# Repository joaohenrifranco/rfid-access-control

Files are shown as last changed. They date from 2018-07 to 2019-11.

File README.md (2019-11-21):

_Note: this repo is not being actively maintained_
# RFID Access Control
Access control system developed to log each entrance and exit of internal rooms at a lab located at Federal University of Rio de Janeiro (UFRJ).

## Server
Django based server that provides a RESTful API for authentication and logging. Also provides a control panel made with Django Admin.

Code and more detailed info inside `server/`
## Client
Developed and tested for Arduino Mega using [PlatformIO](https://platformio.org/).

Works primarily with RFID readers, one for outside and one for inside, checking if the read UID is registered in server database and has sufficient privileges for unlocking the desired room.

Password authentication is optional through a 4x3 matrix keyboard, providing some kind of security.

Code and more detailed info inside `client/`

## Extras

### Front door "smart doorbell"
Developed in parallel with this project. Works with a RaspberryPi 3 located at the front door and a VoIP server (Asterisk) for live video transferring.

When doorbell is rang, the raspberry calls all people inside the lab, with some preconfigured order. They can take the call, check the camera and open the door if desired. All with their smartphone, PC or any other SIP-capable device.

Employees can automatically get in with their RFID tags registered in this system.

Also, everything is logged through this API.

For code and more info on that check the repositories below:

 - [Asterisk server](https://github.com/joaohenriquef/asterisk-smartdoor)
 - [Raspberry client](https://github.com/joaohenriquef/rasp-smartdoor)

## Disclaimer

Note that it is not made with security in mind and its main purpouse is internal logging, therefore it may be vulnerable to external attackers.

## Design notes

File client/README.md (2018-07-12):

# Client

## Disclaimer
Every instruction shown below is only valid for this single project. Any changes on code, hardware or others may cause malfunctions or adding other requirements.

## Hardware requirements
For a single Arduino client you will need:
* 1x Arduino MEGA 2560;
* 1x Ethernet Shield W5100 (for communicating with server);
* 2x RFID Reader MFRC-522 (for reading UIDs);
* 2x RGB LED;
* 1x 5V active buzzer;
* 1x TCRT5000 optical sensor (for checking if the door is closed or not);
* 1x LM2596 DC/DC converter (for supplying Arduino through a 12V power source);
* 1x MOSFET IRF540N (for unlocking the door);
* 3x 150Ω resistors (for RED pins on LEDs and infra-red LED);
* 2x 220Ω resistors (for GREEN pins on LEDs);
* 2x 470Ω resistors (for BLUE pins on LEDs);
* 1x 10KΩ resistor (for LDR);
* 1x 4x3 matrix keypad (optional);
* 1x Custom shield*

*For further information on this, check the [Custom shield](#custom-shield) section on this file.

## Implementation
A single client consists on two "blocks" of equipment. One block inside the room and, the other, outside, as shown below:

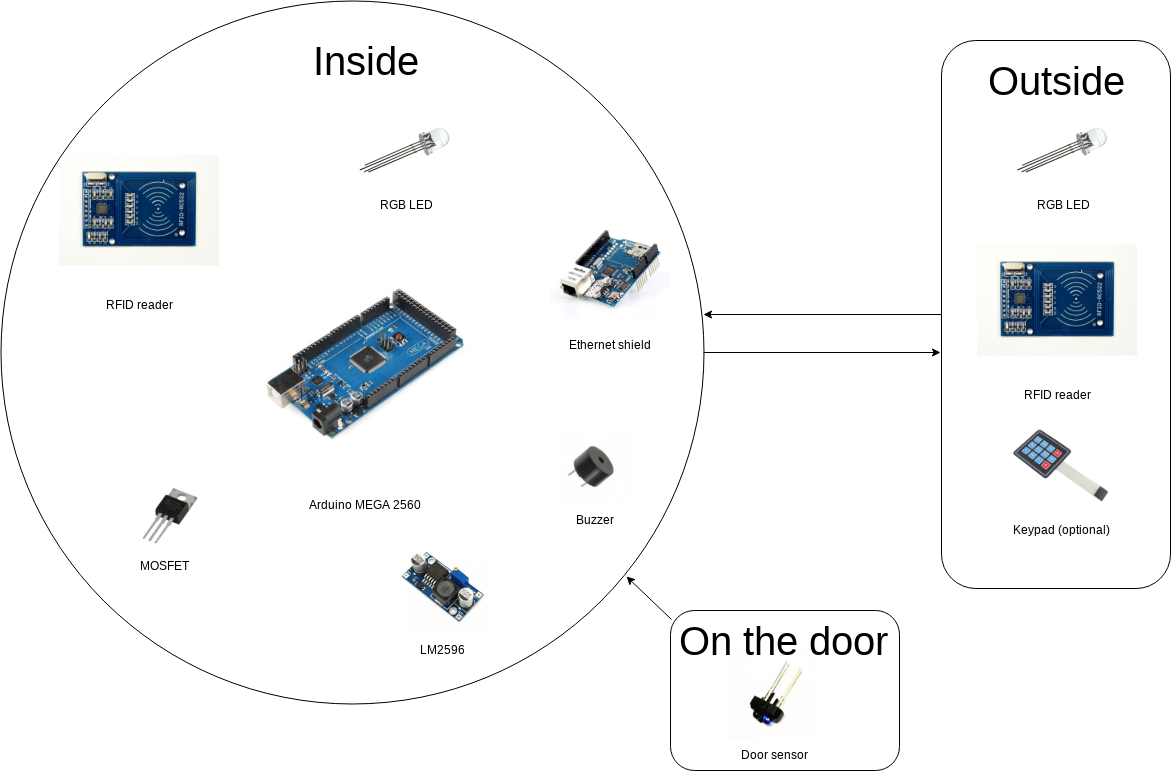
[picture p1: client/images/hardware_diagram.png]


## Algorithm
The Arduino code is pretty simple and works as the diagram below:
* Setup:

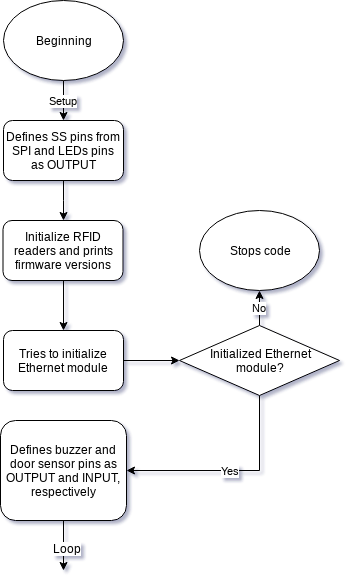
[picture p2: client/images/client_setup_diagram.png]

* Loop:

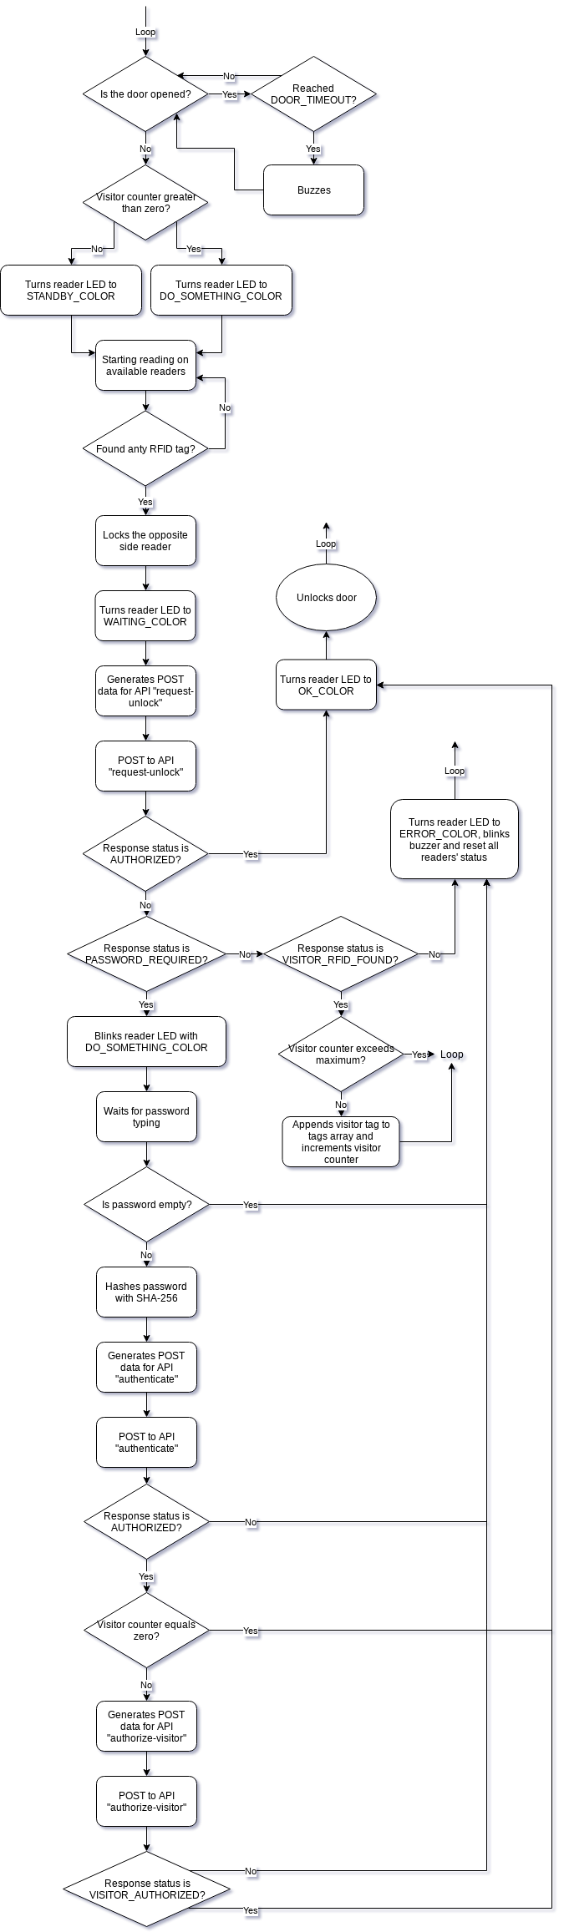
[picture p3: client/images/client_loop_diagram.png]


## Custom shield
In order to ease implementation, a custom PCB was designed with [KiCad](http://kicad-pcb.org/), in the shape of an Arduino Mega Shield. The electrical schematic is the following and all the files related to the PCB design may be found inside `custom_shield/`:

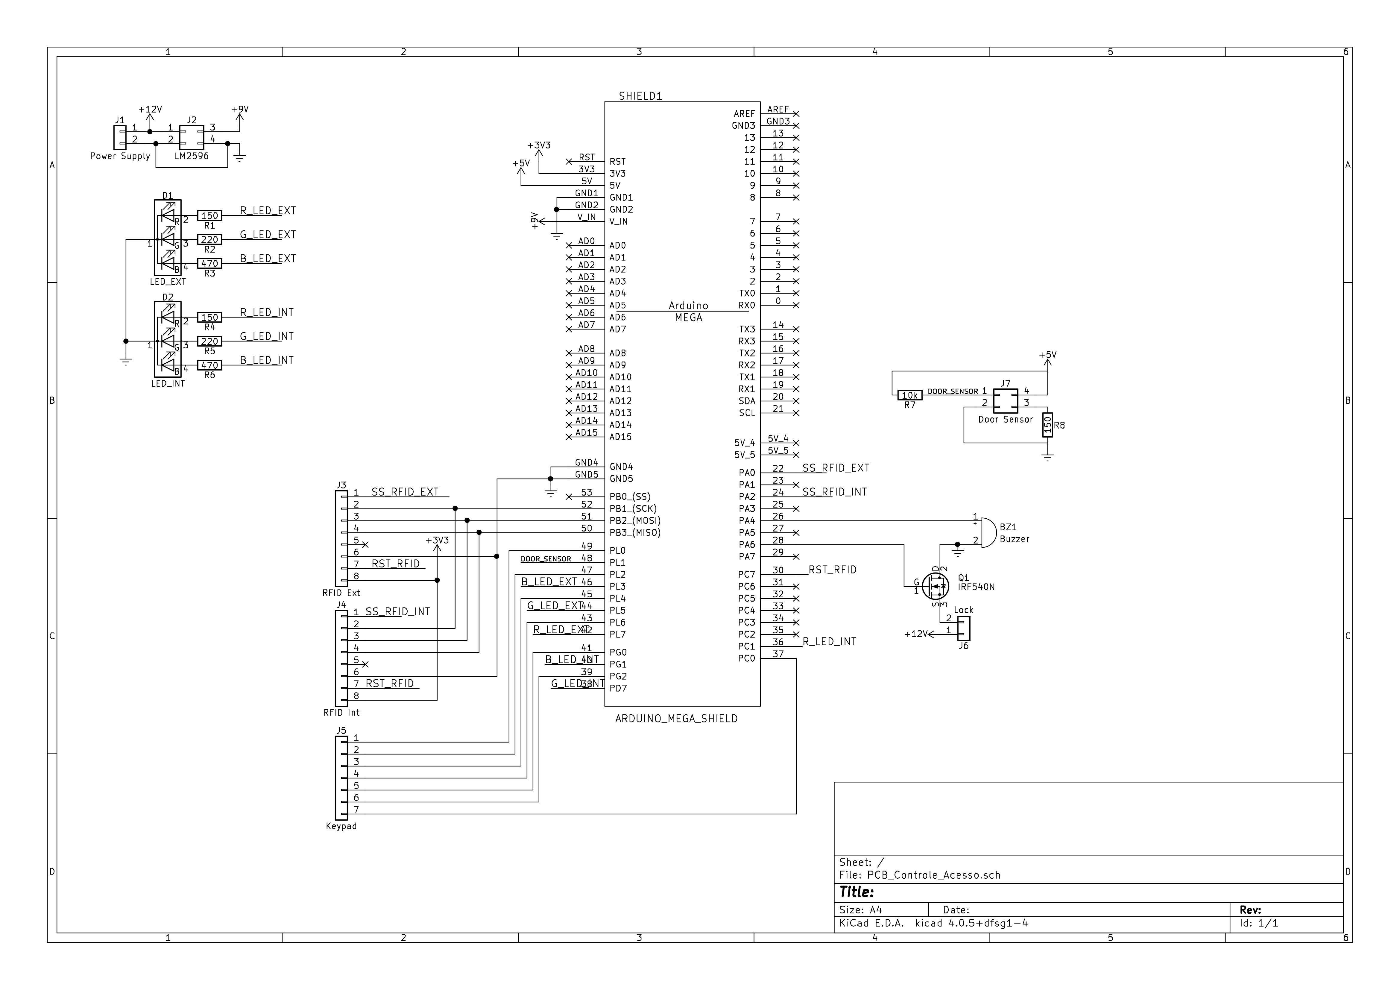
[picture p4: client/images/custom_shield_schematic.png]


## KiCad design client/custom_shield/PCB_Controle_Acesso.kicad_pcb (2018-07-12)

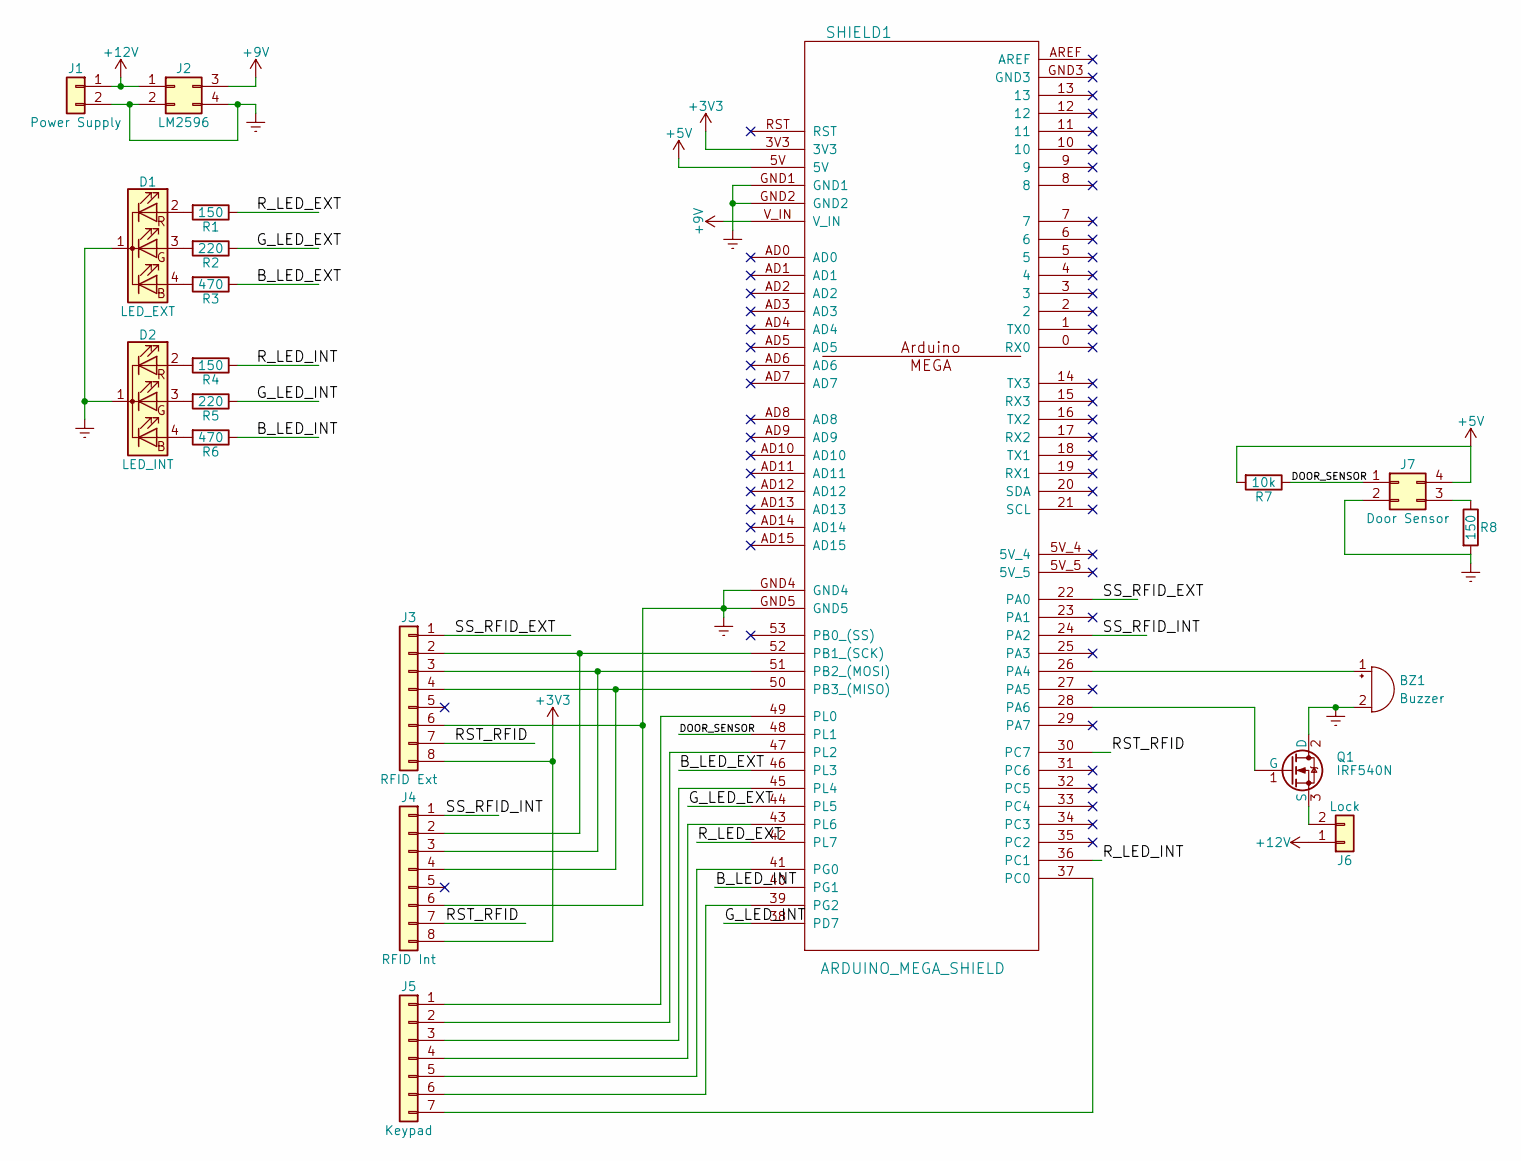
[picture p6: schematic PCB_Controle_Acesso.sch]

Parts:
BZ1: Buzzer; Buzzer_12x9.5RM7.6
D1: LED_EXT; Pin_Header_Straight_1x04_Pitch2.54mm
D2: LED_INT; LED_D5.0mm-4
J1: Power Supply; TerminalBlock_Phoenix_MKDS1.5-2pol
J2: LM2596; lm2596
J3: RFID Ext; Pin_Header_Straight_1x08_Pitch2.54mm
J4: RFID Int; RFID-RC522
J5: Keypad; Pin_Header_Straight_1x07_Pitch2.54mm
J6: Lock; TerminalBlock_Phoenix_MKDS1.5-2pol
J7: Door Sensor; Pin_Header_Straight_2x02_Pitch2.54mm
Q1: IRF540N; TO-220-3_Horizontal
R1, R4, R8: 150; R_Axial_DIN0204_L3.6mm_D1.6mm_P7.62mm_Horizontal
R2, R5: 220; R_Axial_DIN0204_L3.6mm_D1.6mm_P7.62mm_Horizontal
R3, R6: 470; R_Axial_DIN0204_L3.6mm_D1.6mm_P7.62mm_Horizontal
R7: 10k; R_Axial_DIN0204_L3.6mm_D1.6mm_P7.62mm_Horizontal
SHIELD1: ARDUINO_MEGA_SHIELD; ARDUINO_MEGA_SHIELD_ETH_MODIFIED

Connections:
+5V: J7.4, R7.2, SHIELD1.5V
+9V: J2.3, SHIELD1.V_IN
+12V: J1.1, J2.1, J6.1
/B_LED_EXT: R3.1, SHIELD1.46 (PL3)
/B_LED_INT: R6.1, SHIELD1.40 (PG1)
/DOOR_SENSOR: J7.1, R7.1, SHIELD1.48 (PL1)
/G_LED_EXT: R2.1, SHIELD1.44 (PL5)
/G_LED_INT: R5.1, SHIELD1.38 (PD7)
/RST_RFID: J3.7, J4.7, SHIELD1.30 (PC7)
/R_LED_EXT: R1.1, SHIELD1.42 (PL7)
/R_LED_INT: R4.1, SHIELD1.36 (PC1)
/SS_RFID_EXT: J3.1, SHIELD1.22 (PA0)
/SS_RFID_INT: J4.1, SHIELD1.24 (PA2)
unnamed: BZ1.1 (-), SHIELD1.26 (PA4)
unnamed: D1.2 (RA), R1.2
unnamed: D1.3 (GA), R2.2
unnamed: D1.4 (BA), R3.2
unnamed: D2.2 (RA), R4.2
unnamed: D2.3 (GA), R5.2
unnamed: D2.4 (BA), R6.2
unnamed: J3.2, J4.2, SHIELD1.52 (PB1_(SCK))
unnamed: J3.3, J4.3, SHIELD1.51 (PB2_(MOSI))
unnamed: J3.4, J4.4, SHIELD1.50 (PB3_(MISO))
unnamed: J5.1, SHIELD1.49 (PL0)
unnamed: J5.2, SHIELD1.47 (PL2)
unnamed: J5.3, SHIELD1.45 (PL4)
unnamed: J5.4, SHIELD1.43 (PL6)
unnamed: J5.5, SHIELD1.41 (PG0)
unnamed: J5.6, SHIELD1.39 (PG2)
unnamed: J5.7, SHIELD1.37 (PC0)
unnamed: J6.2, Q1.3 (S)
unnamed: J7.3, R8.1
unnamed: Q1.1 (G), SHIELD1.28 (PA6)

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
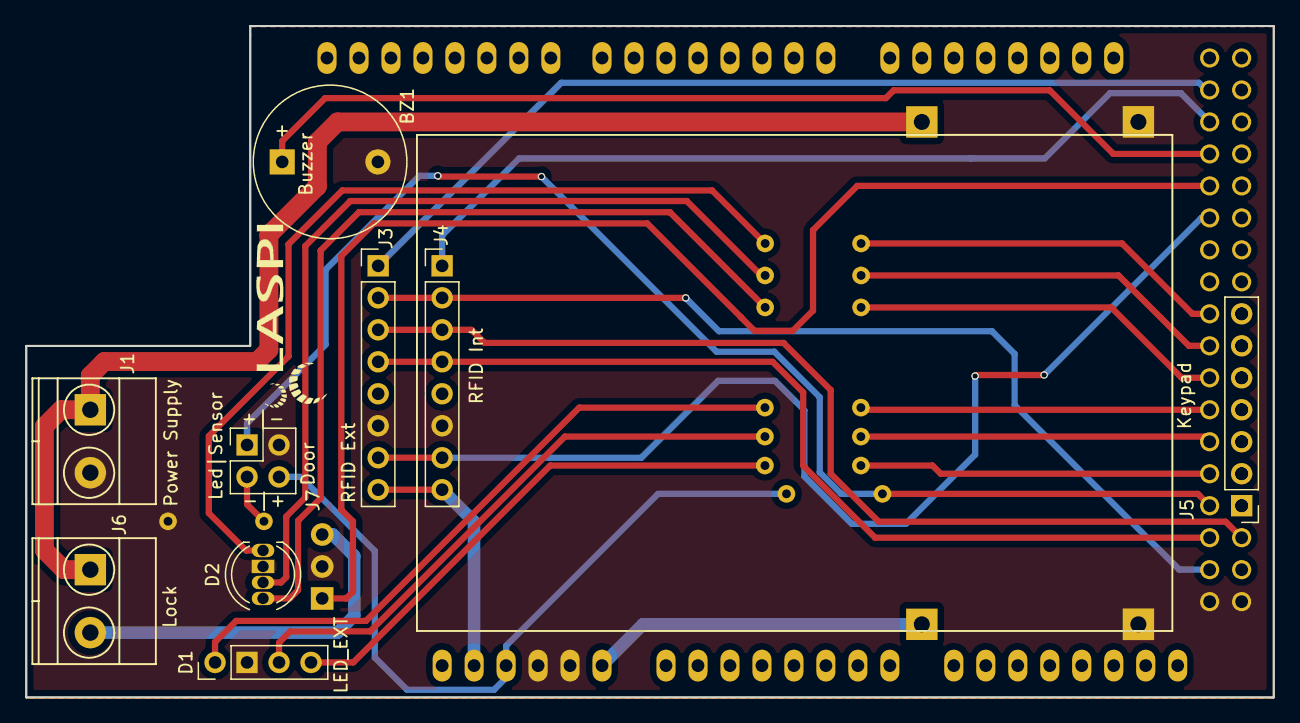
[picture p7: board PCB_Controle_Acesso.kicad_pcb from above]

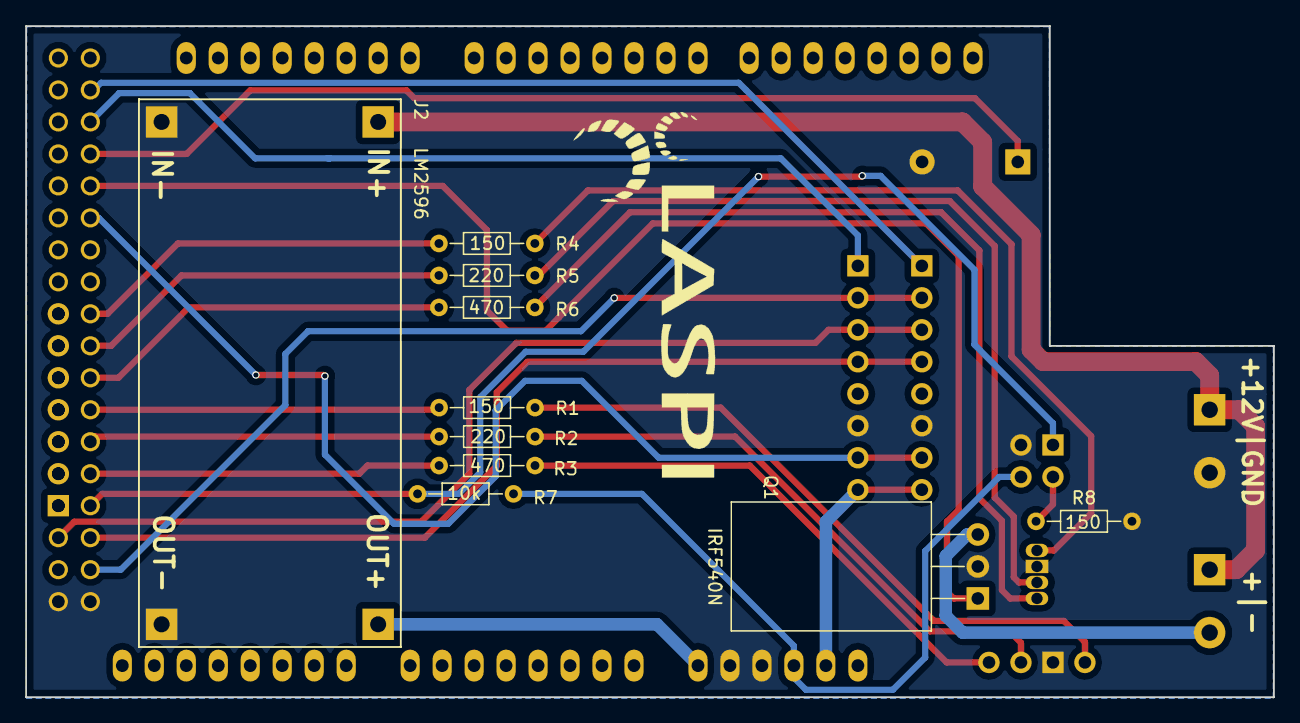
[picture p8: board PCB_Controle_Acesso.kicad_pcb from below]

Board: 2 copper layers, 99.1 x 53.3 mm, 20 parts (10 on the bottom side), 35 nets.

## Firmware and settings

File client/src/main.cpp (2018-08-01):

/*
 *  This code is compatible with Arduino MEGA 2560 R3
 */

/*
 *  Libraries
 */
#include <SPI.h>
#include <stdio.h>
#include <string.h>
#include <MFRC522.h>
#include <Ethernet.h>
#include <Keypad.h>
#include <sha256.h>
#include <ArduinoJson.h>
#include <ArduinoHttpClient.h>

/*
 *  Macros
 */
#define WHO_AM_I "ENSAIOS_REP"
#define MEASURE_NUMBERS 10
#define MAX_VISITOR_NUM 20
#define SERIAL_SPEED 9600
#define MAC_ADDRESS                        \
	{                                      \
		0x00, 0xAA, 0xBB, 0xCC, 0xDE, 0x02 \
	} // Change MAC for individual modules
#define SERVER_IP "192.168.88.41"
#define REQUEST_UNLOCK "/api/request-unlock"
#define AUTHENTICATE "/api/authenticate"
#define AUTHORIZE_VISITOR "/api/authorize-visitor"
#define REQUEST_PORT 80 //Standard HTTP port
#define KEYPAD_LINES 4
#define KEYPAD_COLUMNS 3
#define KEYS                                                                 \
	{                                                                        \
		{'1', '2', '3'}, {'4', '5', '6'}, {'7', '8', '9'}, { '*', '0', '#' } \
	}
#define END_OF_PASSWORD '#'
#define QUIT_TYPING '*'
#define NUM_READERS 2
byte BLACK[] = {0, 0, 0}; //Turn LED off
byte BLUE[] = {0, 0, HIGH};
byte GREEN[] = {0, HIGH, 0};
byte AQUA[] = {0, HIGH, HIGH}; //Light blue
byte RED[] = {HIGH, 0, 0};
byte FUCHSIA[] = {HIGH, 0, HIGH}; //Kinda purple
byte YELLOW[] = {HIGH, HIGH, 0};
byte WHITE[] = {HIGH, HIGH, HIGH};
#define WAITING_COLOR YELLOW
#define OK_COLOR GREEN
#define ERROR_COLOR RED
#define STANDBY_COLOR WHITE
#define DO_SOMETHING_COLOR BLUE
#define DOOR_UNLOCK_TIME 2000
#define TIMEOUT_VISITOR 20000
#define TIMEOUT_DOOR 60000
#define TIMEOUT_PASSWORD 5000

/*
 *	Server Error Codes
 */
#define UNKNOWN_ERROR -1
#define AUTHORIZED 0
#define RFID_NOT_FOUND 1
#define INSUFFICIENT_PRIVILEGES 2
#define WRONG_PASSWORD 3
#define PASSWORD_REQUIRED 4
#define VISITOR_RFID_FOUND 5
#define VISITOR_AUTHORIZED 6
#define VISITOR_RFID_NOT_FOUND 7
#define ROOM_NOT_FOUND 8
#define OPEN_DOOR_TIMEOUT 9

/*
 *  Pins
 */
#define LED_IN_R 36
#define LED_IN_G 38
#define LED_IN_B 40
#define LED_OUT_R 42
#define LED_OUT_G 44
#define LED_OUT_B 46
#define PIN_SENSOR 48
#define PIN_BUZZER 26
#define DOOR_PIN 28
#define RST_PIN 30
#define KEYPAD_LIN_PINS \
	{                   \
		37, 39, 41, 43  \
	}
#define KEYPAD_COL_PINS \
	{                   \
		45, 47, 49      \
	}

// Macros for reference only
#define MISO_PIN 50
#define MOSI_PIN 51
#define SCK_PIN 52

//	SS pins
const byte SS_PIN_ETHERNET = 10;
const byte SS_PIN_OUTSIDE = 22;
const byte SS_PIN_INSIDE = 24;

//	Redefining Ethernet SS pin
#ifdef ETHERNET_SHIELD_SPI_CS
#undef ETHERNET_SHIELD_SPI_CS
#endif
#define ETHERNET_SHIELD_SPI_CS SS_PIN_ETHERNET

/*
 *  Declaring the RFID modules
 */
const byte ssPins[] = {SS_PIN_OUTSIDE, SS_PIN_INSIDE};
MFRC522 readers[NUM_READERS];
bool readers_locked[2] = {false, false};
char readers_id[2] = {'o', 'i'};

/*
 *  Declaring IP, MAC and the ethernet client itself
 */
// TODO: FIX AUTOMATIC MAC, FOLLOWING COMMENTED LINES CRASH ETHERNET
// #if defined(WIZ550io_WITH_MACADDRESS)
// ;
// #else
byte mac[] = MAC_ADDRESS;

/*
 *  Declaring and initializing the keypad (4x3)
 */
char keys[KEYPAD_LINES][KEYPAD_COLUMNS] = KEYS;
byte keyPadLinPins[KEYPAD_LINES] = KEYPAD_LIN_PINS;
byte keyPadColPins[KEYPAD_COLUMNS] = KEYPAD_COL_PINS;
Keypad keyPad = Keypad(makeKeymap(keys), keyPadLinPins, keyPadColPins, KEYPAD_LINES, KEYPAD_COLUMNS);

/*
 *	Global vars for visitors
 */
byte visitor_counter = 0;
String tagsArray[MAX_VISITOR_NUM];
unsigned long visitorInitTime = 0;

/*
 *  void WriteRGB (byte color[], char inside_outside);
 *
 *  Description:
 *  - Procedure that changes the inside or outside LED color
 *
 *  Inputs/Outputs:
 *  [INPUT] byte color[]: array that contatins red, green and blue values
 *
 *  Returns:
 *  -
 */
void WriteRGB(byte color[], char inside_outside)
{
	if (inside_outside == 'i')
	{
		byte pins[] = {LED_IN_R, LED_IN_G, LED_IN_B};
		for (byte i = 0; i < 3; i++)
			digitalWrite(pins[i], color[i]);
	}
	else if (inside_outside == 'o')
	{
		byte pins[] = {LED_OUT_R, LED_OUT_G, LED_OUT_B};
		for (byte i = 0; i < 3; i++)
			digitalWrite(pins[i], color[i]);
	}
}

/*
 *	Write function header
 */
void WriteReaderLED(byte color[])
{
	for (byte i = 0; i < 2; i++)
	{
		if (readers_locked[i] == true)
		{
			WriteRGB(ERROR_COLOR, readers_id[i]);
		}
		else
		{
			WriteRGB(color, readers_id[i]);
		}
	}
}

/*
 *	void BlinkRGB (byte n_times, byte delay_time, byte blink_color [], byte end_color [], char readerPosition);
 *
 *  Description:
 *  - Blinks RGB LED in "readerPosition" from "blink_color" to "end_color" "n_times" times within a "delay_time" time
 *
 *  Inputs/Outputs:
 *  [INPUT] byte n_times: number of times the LED will blink
 * 	[INPUT] byte delay_time: time between blinks
 *  [INPUT] byte blink_color []: the LED color when blinking
 *  [INPUT] byte end_color []: the LED color when it ends
 *  [INPUT] char readerPosition: which LED should blink
 *
 *  Returns:
 *  -
 */
void BlinkRGB(byte n_times, byte delay_time, byte blink_color[], byte end_color[], char readerPosition)
{
	for (byte i = 0; i < n_times; i++)
	{
		WriteReaderLED(blink_color);
		delay(delay_time);
		WriteReaderLED(end_color);
		delay(delay_time);
	}
}

/*
 *  String UID_toStr (byte *buffer, byte bufferSize);
 *
 *  Description:
 *  - Function that converts the UID read from the RFID module to hex string
 *
 *  Inputs/Outputs:
 *  [INPUT] byte *buffer: from RFID module
 * 	[INPUT] byte bufferSize: size of UID
 *
 *  Returns:
 *  [String] The UID tag itself
 */
String UID_toStr(byte *buffer, byte bufferSize)
{
	String aux = "";
	for (byte i = 0; i < bufferSize; i++)
	{
		aux.concat(String(buffer[i] < 0x10 ? "0" : ""));
		aux.concat(String(buffer[i], HEX));
	}
	return aux;
}

/*
 *	void Buzz (bool activate);
 *
 *  Description:
 *  - Switches buzzer on or off
 *
 *  Inputs/Outputs:
 *  [INPUT] bool activate: tells if it should be switched on or off
 *
 *  Returns:
 *  -
 */
void Buzz(bool activate)
{
	digitalWrite(PIN_BUZZER, activate);
}

/*
 *	Build description (TODO)
 */
void BlinkBuzzer(byte n_times, byte delay_time)
{
	for (byte i = 0; i < n_times; i++)
	{
		Buzz(true);
		delay(delay_time);
		Buzz(false);
		delay(delay_time);
	}
}

/*
 *  String ReadRFIDTags (char *entering_or_leaving);
 *
 *  Description:
 *  - Function to read UID tags from all readers
 *
 *  Inputs/Outputs:
 *  [OUTPUT] char *entering_or_leaving: indicates if the person is entering or leaving the room
 *
 *  Returns:
 *  [String] The UID tag itself in uppercase or empty string
 */
String ReadRFIDTags(char *entering_or_leaving)
{
	digitalWrite(SS_PIN_ETHERNET, HIGH);
	*entering_or_leaving = 255;
	String aux = "";
	for (byte i = 0; i < NUM_READERS; i++)
	{
		if (readers_locked[i] == false)
		{
			digitalWrite(SS_PIN_INSIDE, HIGH);
			digitalWrite(SS_PIN_OUTSIDE, HIGH);
			digitalWrite(ssPins[i], LOW);
			aux = "";
			if (readers[i].PICC_IsNewCardPresent() && readers[i].PICC_ReadCardSerial())
			{
				aux = UID_toStr(readers[i].uid.uidByte, readers[i].uid.size);
				BlinkBuzzer(1, 10);
				*entering_or_leaving = i;
			}
			if (aux != "")
				return aux;
		}
	}
	return aux;
}

/*
 *	Build description (TODO)
 */
void BuzzTimer(byte delayTime)
{
	Buzz(true);
	delay(delayTime);
	Buzz(false);
}

/*
 *  String GetPassword ();
 *
 *  Description:
 *  - Function to get a sequence of characters from keypad until the END_OF_PASSWORD
 *  or QUIT_TYPING characters are pressed
 *
 *  Inputs/Outputs:
 *  -
 *
 *  Returns:
 *  [String] The password typed until the END_OF_PASSWORD character
 */
String GetPassword()
{
	String aux = "";
	char c = keyPad.getKey();
	unsigned long initial_timer = millis();
	while (c != END_OF_PASSWORD)
	{
		if (millis() >= initial_timer + TIMEOUT_PASSWORD)
		{
			return "";
		}
		if (c == QUIT_TYPING)
		{
			BlinkBuzzer(1, 50);
			return "";
		}
		if (c)
		{
			initial_timer = millis();
			BlinkBuzzer(1, 50);
			BlinkRGB(1, 75, BLACK, DO_SOMETHING_COLOR, 'o');
			aux.concat(c);
		}
		c = keyPad.getKey();
	}
	BlinkBuzzer(1, 50);
	return aux;
}

/*
 *  String readableHash(uint8_t* hash);
 *
 *  Description:
 *  - Function to convert hashed password to a readable string
 *
 *  Inputs/Outputs:
 *  [INPUT] String hash: the hashed password
 *
 *  Returns:
 *  [String] A 64-character long string with containing the hashed password
 */
String readableHash(uint8_t *hash)
{
	String out = "";
	for (byte i = 0; i < 32; i++)
	{
		out.concat("0123456789abcdef"[hash[i] >> 4]);
		out.concat("0123456789abcdef"[hash[i] & 0xf]);
	}
	return out;
}

/*
 *  String HashedPassword (String password);
 *
 *  Description:
 *  - Function to hash an existing password
 *
 *  Inputs/Outputs:
 *  [INPUT] String password: the plain text password to be hashed
 *
 *  Returns:
 *  [String] The hash function result
 */
String HashedPassword(String password)
{
	Sha256 hash_function;
	uint8_t *hash;
	hash_function.init();
	hash_function.print(password);
	hash = hash_function.result();
	return readableHash(hash);
}

/*
 *  String GenerateUnlockPostData (String uid, byte roomID, byte readerPosition);
 *
 *  Description:
 *  - Generates a JSON format text to send through HTTP POST to REQUEST_UNLOCK
 *
 *  Inputs/Outputs:
 *  [INPUT] String uid: the RFID Tag read by RFID module
 *  [INPUT] byte roomID: the ID of the room where this client is
 *  [INPUT] byte readerPosition: indicates if the person is entering or leaving the room
 *
 *  Returns:
 *  [String] A JSON format text contatining the whole input data
 */
String GenerateUnlockPostData(String uid, String roomID, byte readerPosition)
{
	String aux = "{\n\t\"uid\":\"";
	aux.concat(uid);
	aux.concat("\",\n\t\"roomID\":\"");
	aux.concat(roomID);
	aux.concat("\",\n\t\"readerPosition\":");
	aux.concat(String(readerPosition));
	aux.concat("\n}");
	return aux;
}

/*
 *  String GenerateAuthenticatePostData (String uid, String password, String roomID);
 *
 *  Description:
 *  - Generates a JSON format text to send through HTTP POST to REQUEST_UNLOCK
 *
 *  Inputs/Outputs:
 *  [INPUT] String uid: the RFID Tag read by RFID module
 *	[INPUT] String password: the user's read password
 *
 *  Returns:
 *  [String] A JSON format text contatining the whole input data
 */
String GenerateAuthenticatePostData(String uid, String password, String roomID)
{
	String aux = "{\n\t\"uid\":\"";
	aux.concat(uid);
	aux.concat("\",\n\t\"password\":\"");
	aux.concat(password);
	aux.concat("\",\n\t\"roomID\":\"");
	aux.concat(roomID);
	aux.concat("\"\n}");
	return aux;
}

/*
 *  String GenerateVisitorPostData (String uid, String visitorsUids []);
 *
 *  Description:
 *  - Generates a JSON format text to send through HTTP POST to AUTHORIZE_VISITOR
 *
 *  Inputs/Outputs:
 *  [INPUT] String uid: an employee RFID
 *	[INPUT] String visitorsUids []: an array with all the visitors' RFIDs
 *
 *  Returns:
 *  [String] A JSON format text contatining the whole input data
 */
String GenerateVisitorPostData(String uid, String visitorsUids[], String roomID)
{
	StaticJsonBuffer<200> postDataBuffer;

	JsonObject &jsonRoot = postDataBuffer.createObject();
	jsonRoot["uid"] = uid;
	jsonRoot["roomID"] = roomID;

	JsonArray &VisUID = jsonRoot.createNestedArray("visitorsUids");
	for (byte i = 0; i < visitor_counter; i++)
	{
		VisUID.add(visitorsUids[i]);
	}

	String output;
	jsonRoot.printTo(output);
	return output;
}

/*
 *  byte ParseResponse (String response);
 *
 *  Description:
 *  - Parse the server's response to return numeric status
 *
 *  Inputs/Outputs:
 *  [INPUT] String response: Server's response
 *
 *  Returns:
 *  [byte] Numeric error code from server
 */
byte ParseResponse(String response)
{
	DynamicJsonBuffer jsonBuffer(JSON_OBJECT_SIZE(1) + 20);

	byte status = 255;
	JsonObject &root = jsonBuffer.parseObject(response);
	if (!root.success())
	{
		Serial.println("Parsing response failed!");
		status = 255;
	}
	else
	{
		Serial.println("Parsing successful");
		status = root["status"];
	}
	return status;
}

/*
 *  byte SendPostRequest (String postData, String requestFrom);
 *
 *  Description:
 *  - Does a POST Request
 *
 *  Inputs/Outputs:
 *  [INPUT] String postData: the JSON format POST data
 *  [INPUT] String requestFrom: the API URL
 *
 *  Returns:
 *  [byte] The server's response status
 */
byte SendPostRequest(String postData, String requestFrom)
{
	// long thisTime = millis();

	digitalWrite(SS_PIN_ETHERNET, LOW);
	digitalWrite(SS_PIN_OUTSIDE, HIGH);
	digitalWrite(SS_PIN_INSIDE, HIGH);

	// Serial.print("Tempo de setar pinos: ");
	// Serial.println(millis() - thisTime);
	// thisTime = millis();

	EthernetClient ethClient;
	HttpClient httpClient = HttpClient(ethClient, SERVER_IP, REQUEST_PORT);

	// Serial.print("Tempo de inicialização cliente HTTP: ");
	// Serial.println(millis() - thisTime);
	// thisTime = millis();

	String response = "";
	byte output = 255;
	String contentType = "application/json";
	Serial.println("Sending post...");

	// Serial.print("Tempo até enviar o POST: ");
	// Serial.println(millis() - thisTime);
	// thisTime = millis();

	httpClient.post(requestFrom, contentType, postData);

	// Serial.print("Tempo para enviar o POST: ");
	// Serial.println(millis() - thisTime);
	// thisTime = millis();

	response = httpClient.responseBody();
	Serial.print("Response: ");
	Serial.println(response);

	// Serial.print("Tempo para pegar o response: ");
	// Serial.println(millis() - thisTime);
	// thisTime = millis();

	output = ParseResponse(response);

	// Serial.print("Tempo para parsear o response: ");
	// Serial.println(millis() - thisTime);
	// thisTime = millis();

	httpClient.endRequest();
	return output;
}

/*
 *  bool BooleanMode (bool *array);
 *
 *  Description:
 *  - Returns the mode of a boolean array
 *
 *  Inputs/Outputs:
 *  [INPUT] bool *array: an array of booleans
 *
 *  Returns:
 *  [bool] The array's mode
 */
bool BooleanMode(bool *array)
{
	byte countTrue = 0;
	byte countFalse = 0;
	for (byte i = 0; i < MEASURE_NUMBERS; i++)
	{
		if (array[i] == true)
			countTrue++;
		else
			countFalse++;
	}
	return countTrue > countFalse;
}

/*
 *  bool DoorOpened ();
 *
 *  Description:
 *  - Checks if the door is opened
 *
 *  Inputs/Outputs:
 *  -
 *
 *  Returns:
 *  [bool] Is the door opened?
 */
bool DoorOpened()
{
	bool measures[MEASURE_NUMBERS];
	for (byte i = 0; i < MEASURE_NUMBERS; i++)
	{
		measures[i] = digitalRead(PIN_SENSOR);
	}
	return BooleanMode(measures);
}

/*
  *	Write header
  */
void ResetStatus(void)
{
	readers_locked[0] = false;
	readers_locked[1] = false;
	visitor_counter = 0;
}

/*
 *	Write header
 */
void CheckVisitorTimeout(void)
{
	Serial.print("Time: ");
	Serial.println(millis() - visitorInitTime);
	if ((millis() - visitorInitTime) >= TIMEOUT_VISITOR)
	{
		ResetStatus();
		Serial.println("Checou timeout");
	}
}

/*
 *	Write header
 */
void CheckDoorTimeout(void)
{
	bool opened = DoorOpened();
	unsigned long timer = millis();
	bool previous_lock[2] = {readers_locked[0], readers_locked[1]};
	while (opened)
	{
		Serial.println("=== PORTA ABERTA! ===");
		readers_locked[0] = true;
		readers_locked[1] = true;
		WriteReaderLED(ERROR_COLOR);
		if (millis() >= timer + TIMEOUT_DOOR)
		{
			Buzz(true);
		}
		opened = DoorOpened();
	}
	digitalWrite(DOOR_PIN, HIGH);
	WriteReaderLED(STANDBY_COLOR);
	Serial.println("- Porta fechada...");
	Buzz(false);
	readers_locked[0] = previous_lock[0];
	readers_locked[1] = previous_lock[1];
}

/*
 *  void UnlockDoor (void);
 *
 *  Description:
 *  - Procedure to unlock the door
 */
void UnlockDoor(void)
{
	digitalWrite(DOOR_PIN, LOW);
	delay(DOOR_UNLOCK_TIME);
	digitalWrite(DOOR_PIN, HIGH);
	ResetStatus();
}

/*
 *	Write header
 */
void ErrorExit(void)
{
	WriteReaderLED(ERROR_COLOR);
	BlinkBuzzer(3, 50);
	BuzzTimer(200);
	ResetStatus();
	delay(1000);
}

/*
 *  Setup
 */
void setup()
{

	// Turn LEDs into FUCHSIA to print that the setup has been going on
	WriteReaderLED(FUCHSIA);

	// Starts serial communication for debugging purposes

	Serial.begin(SERIAL_SPEED);

	Serial.println("=== Beginning Setup...");
	Serial.println("-- Setting SPI SS pins...");

	pinMode(SS_PIN_INSIDE, OUTPUT);
	pinMode(SS_PIN_OUTSIDE, OUTPUT);

	Serial.println("-- Setting LEDs pins as output...");

	pinMode(LED_IN_R, OUTPUT);
	pinMode(LED_IN_G, OUTPUT);
	pinMode(LED_IN_B, OUTPUT);
	pinMode(LED_OUT_R, OUTPUT);
	pinMode(LED_OUT_G, OUTPUT);
	pinMode(LED_OUT_B, OUTPUT);
	pinMode(DOOR_PIN, OUTPUT);
	digitalWrite(DOOR_PIN, HIGH);

	Serial.println("-- Initializing RFID modules...");

	SPI.begin();
	for (byte i = 0; i < NUM_READERS; i++)
	{
		digitalWrite(SS_PIN_INSIDE, HIGH);
		digitalWrite(SS_PIN_OUTSIDE, HIGH);
		digitalWrite(ssPins[i], LOW);
		readers[i].PCD_Init(ssPins[i], RST_PIN);
		Serial.print("-- Reader ");
		Serial.print(i + 1);

		Serial.print(" initialized!\n- Version: ");
		readers[i].PCD_DumpVersionToSerial();
	}

	Serial.println("-- Initializing Ethernet module...");

	for (byte i = 0; i < NUM_READERS; i++)
	{
		digitalWrite(ssPins[i], HIGH);
	}
	digitalWrite(SS_PIN_ETHERNET, LOW);

	if (Ethernet.begin(mac) == 0)
	{
		WriteReaderLED(ERROR_COLOR);
		Serial.println("Failed to configure Ethernet using DHCP");
		delay(1000);
		setup();
	}

	Serial.print("- My MAC: ");
	Serial.print(mac[0], HEX);
	Serial.print(":");
	Serial.print(mac[1], HEX);
	Serial.print(":");
	Serial.print(mac[2], HEX);
	Serial.print(":");
	Serial.print(mac[3], HEX);
	Serial.print(":");
	Serial.print(mac[4], HEX);
	Serial.print(":");
	Serial.print(mac[5], HEX);
	Serial.println();
	Serial.print("- My IP: ");
	Serial.println(Ethernet.localIP());

	// Initializes the sensor
	Serial.println("-- Setting sensor pin as input...");
	pinMode(PIN_SENSOR, INPUT);
	// Initializes the buzzer
	Serial.println("-- Setting buzzer pin as output...");
	pinMode(PIN_BUZZER, OUTPUT);
	WriteReaderLED(STANDBY_COLOR);
}

/*
 *  Loop
 */
void loop()
{
	/*  Full code for Arduino Client (still in development) */
	String pw = "";
	String tag = "";
	byte status = 255;
	String hashed = "";
	String output = "";
	byte readerPosition = 255;
	String postData = "";
	String employeeTag = "";
	char entering_or_leaving = 255; //0 (ZERO) indicates entering and 1 (ONE) indicates leaving

	CheckDoorTimeout();

	// Standby mode
	if (visitor_counter == 0)
		WriteReaderLED(STANDBY_COLOR);
	else
	{
		WriteReaderLED(DO_SOMETHING_COLOR);
	}

	// Starts to read
	Serial.print("\n=== Starting to read...");
	while (tag == "")
	{
		Serial.print(".");
		if (visitor_counter > 0)
			CheckVisitorTimeout();
		delay(50);
		tag = ReadRFIDTags(&entering_or_leaving);
	}
	Serial.print("\nUID Tag: ");
	Serial.println(tag);
	// Found an UID. Turns one side to WAITING_MODE and the other to BLOCKED_MODE
	if (entering_or_leaving == 0)
		readers_locked[1] = true;
	else
		readers_locked[0] = true;
	WriteReaderLED(WAITING_COLOR);
	// Generates POST data
	Serial.println("-- Generating POST data...");
	postData = GenerateUnlockPostData(tag, WHO_AM_I, entering_or_leaving);
	Serial.println(postData);
	// Sends request to REQUEST_UNLOCK and gets response
	status = SendPostRequest(postData, REQUEST_UNLOCK);
	Serial.print("-- Status: ");
	Serial.println(status);
	// If already authorized, unlocks door
	if (status == AUTHORIZED)
	{
		WriteReaderLED(OK_COLOR);
		UnlockDoor();
	}
	// If needs password, blinks OK_COLOR and asks for typing
	else if (status == PASSWORD_REQUIRED)
	{
		// Copies read tag to employee tag
		employeeTag = tag;
		// Blinks DO_SOMETHING_COLOR
		BlinkRGB(1, 50, BLACK, DO_SOMETHING_COLOR, readerPosition);
		Serial.println("-- Waiting for password...");
		// Gets password
		pw = GetPassword();
		Serial.print("-- Password: ");
		Serial.println(pw);
		if (pw == "")
		{
			ErrorExit();
			return;
		}
		// Blinks WAITING_COLOR once password is read
		BlinkRGB(2, 250, BLACK, WAITING_COLOR, readerPosition);
		// Hashes password
		Serial.println("-- Hashing password...");
		hashed = HashedPassword(pw);
		Serial.print("-- Hashed password (SHA-256): ");
		Serial.println(hashed);
		// Generates POST data for AUTHENTICATE API
		Serial.println("-- Generating POST data...");
		postData = GenerateAuthenticatePostData(tag, hashed, WHO_AM_I);
		Serial.println(postData);
		// Sends POST data to AUTHENTICATE API
		status = SendPostRequest(postData, AUTHENTICATE);
		Serial.print("-- Status: ");
		Serial.println(status);
		// If authorized
		if (status == AUTHORIZED)
		{
			Serial.print("Numero do contador: ");
			Serial.println(visitor_counter);
			Serial.print("Array: ");
			for (byte j = 0; j < visitor_counter; j++)
			{
				Serial.println(j);
				Serial.println(tagsArray[j]);
			}
			// Checks if there's any visitor on tagsArray
			if (visitor_counter == 0)
			{
				WriteReaderLED(OK_COLOR);
				UnlockDoor();
			}
			// If there are visitor tags
			else
			{
				//	Generating POST data for visitors
				Serial.println("-- Generating Visitor POST data...");
				postData = GenerateVisitorPostData(employeeTag, tagsArray, WHO_AM_I);
				Serial.println(postData);
				//	Sending POST to visitors API
				status = SendPostRequest(postData, AUTHORIZE_VISITOR);
				Serial.print("-- Status: ");
				Serial.println(status);
				if (status == VISITOR_AUTHORIZED)
				{
					WriteReaderLED(OK_COLOR);
					UnlockDoor();
				}
				else
				{
					ErrorExit();
				}
			}
		}
		else
		{
			ErrorExit();
		}
	}
	else if (status == VISITOR_RFID_FOUND)
	{
		if (visitor_counter < MAX_VISITOR_NUM)
		{
			visitorInitTime = millis();
			Serial.println("Registering visitor...");
			tagsArray[visitor_counter] = tag;
			Serial.println(tagsArray[visitor_counter]);
			visitor_counter++;
		}
	}
	else
	{
		ErrorExit();
	}
}

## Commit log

2018-01-25 Added a procedure for RGB LED
2018-01-25 Add client-server schematic image
2018-01-25 Add flowchart to README.md
2018-02-21 Update request response flowchart
2018-02-22 Added visitor card identification flow to chart
2018-02-26 Remove debug prints
2018-03-01 Added OpenedDoor and Buzzer funcions
    [main.cpp]
2018-03-07 Changed LED blinking procedure
2018-03-07 Migrated to Arduino Mini Pro 5V/16MHz
2018-03-07 FIxed "BlinkRGB" not declared issue
    [main.cpp]
2018-03-08 Code adapted for Arduino Pro Mini (issues w/ Ethernet)
    [main.cpp]
2018-03-09 Partial fix for arduino mini
    [main.cpp]
2018-03-21 Adapted code to Arduino MEGA 2560
2018-06-19 Make RFID query case insensitive
2018-07-10 Fixed issues with posting
    [main.cpp]
2018-07-12 Solved minor security issues
    [main.cpp]
2018-07-12 Updated client README
    [PCB_Controle_Acesso.kicad_pcb, PCB_Controle_Acesso.sch]
2018-07-27 Tried to fix minor issues w/ response time
    [main.cpp]
